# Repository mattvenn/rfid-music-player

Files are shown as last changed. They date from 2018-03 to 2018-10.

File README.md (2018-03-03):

# rfid music player

## components

* teensy 3.2
* adafruit i2s amp
* rfid rc522 reader
* sd card breakout
* string of leds - currently ws2812, but need to switch to a clocked version for
 compatibility with audio library.

## pin allocations

    teensy          i/o
    6               led data out
    7               mosi sd and rfid reader
    9               i2s bclk
    10              cs sd card
    12              miso sd and rfid

    14              sck sd and rfid
    15              rfid cs
    16              rfid reset
    21 (A7)         vol pot in
    22              i2s din
    23              i2s lrc

    3.3v            rfid psu and positive vol pot
    vin (5v)        i2s amp psu, led string +5v

## sd pinout

    1           n/c
    2           cs
    3           mosi    
    4           3.3v
    5           clk
    6           gnd
    7           miso
    8           n/c

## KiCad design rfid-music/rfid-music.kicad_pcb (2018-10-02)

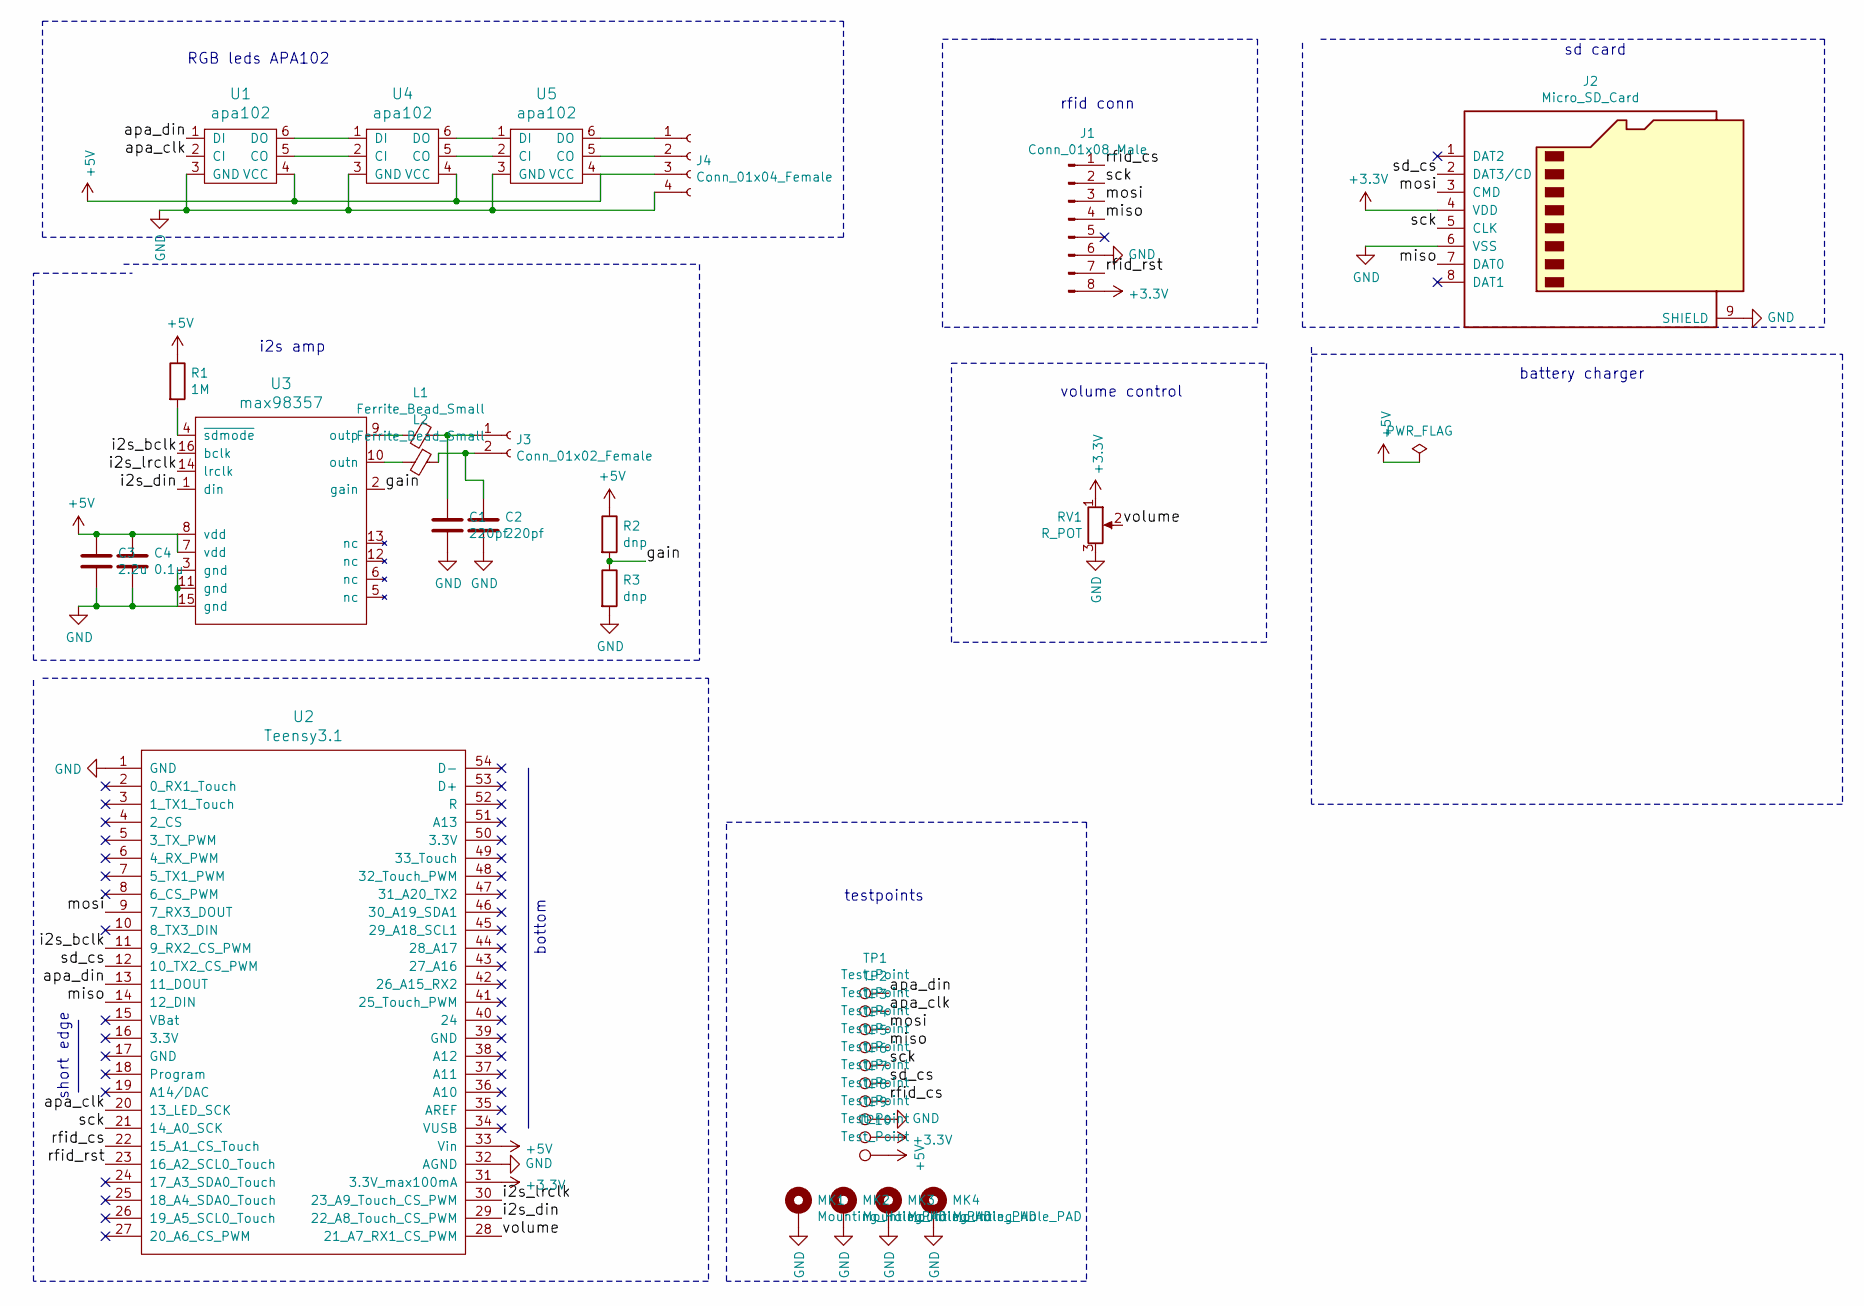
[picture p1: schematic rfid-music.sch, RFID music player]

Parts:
C1, C2: 220pf; C_0805_2012Metric
C3: 2.2u; C_0805_2012Metric
C4: 0.1u; C_0805_2012Metric
J1: Conn_01x08_Male; PinHeader_1x08_P2.54mm_Vertical
J2: Micro_SD_Card; microSD_HC_Hirose_DM3D-SF; farnell # 1764377
J3: Conn_01x02_Female; PinHeader_1x02_P2.54mm_Vertical
J4: Conn_01x04_Female; PinHeader_1x04_P2.54mm_Vertical
L1, L2: Ferrite_Bead_Small; L_0805_2012Metric
MK1, MK2, MK3, MK4: Mounting_Hole_PAD; MountingHole_3.2mm_M3_Pad
R1: 1M; R_0805_2012Metric
R2, R3: dnp; R_0805_2012Metric
RV1: R_POT; Potentiometer_Bourns_3314S_Horizontal; farnell # 1696070
TP1, TP2, TP3, TP4, TP5, TP6, TP7, TP8, TP9, TP10: Test_Point; Pin_D0.7mm_L6.5mm_W1.8mm_FlatFork
U1, U4, U5: apa102
U2: Teensy3.1; teensy31
U3: max98357; QFN-16-1EP_3x3mm_P0.5mm_EP2.7x2.7mm_ThermalVias

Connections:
+3V3: J1.8, J2.4 (VDD), RV1.1, TP9.1, U2.31 (3.3V_max100mA)
+5V: C3.1, C4.1, J4.3, R1.1, R2.1, TP10.1, U1.4 (VCC), U2.33 (Vin), U3.7 (vdd), U3.8 (vdd), U4.4 (VCC), U5.4 (VCC)
/apa_clk: TP2.1, U1.2 (CI), U2.20 (13_LED_SCK)
/apa_din: TP1.1, U1.1 (DI), U2.13 (11_DOUT)
/gain: R2.2, R3.1, U3.2 (gain)
/i2s_bclk: U2.11 (9_RX2_CS_PWM), U3.16 (bclk)
/i2s_din: U2.29 (22_A8_Touch_CS_PWM), U3.1 (din)
/i2s_lrclk: U2.30 (23_A9_Touch_CS_PWM), U3.14 (lrclk)
/miso: J1.4, J2.7 (DAT0), TP4.1, U2.14 (12_DIN)
/mosi: J1.3, J2.3 (CMD), TP3.1, U2.9 (7_RX3_DOUT)
/rfid_cs: J1.1, TP7.1, U2.22 (15_A1_CS_Touch)
/rfid_rst: J1.7, U2.23 (16_A2_SCL0_Touch)
/sck: J1.2, J2.5 (CLK), TP5.1, U2.21 (14_A0_SCK)
/sd_cs: J2.2 (DAT3/CD), TP6.1, U2.12 (10_TX2_CS_PWM)
/volume: RV1.2, U2.28 (21_A7_RX1_CS_PWM)
GND: C1.2, C2.2, C3.2, C4.2, J1.6, J2.6 (VSS), J2.9 (SHIELD), J4.4, MK1.1, MK2.1, MK3.1, MK4.1, R3.2, RV1.3, TP8.1, U1.3 (GND), U2.1 (GND), U2.32 (AGND), U3.3 (gnd), U3.11 (gnd), U3.15 (gnd), U4.3 (GND), U5.3 (GND)
unnamed: C1.1, J3.1, L1.1
unnamed: C2.1, J3.2, L2.1
unnamed: J4.1, U5.6 (DO)
unnamed: J4.2, U5.5 (CO)
unnamed: L1.2, U3.9 (outp)
unnamed: L2.2, U3.10 (outn)
unnamed: R1.2, U3.4 (~sdmode)
unnamed: U1.5 (CO), U4.2 (CI)
unnamed: U1.6 (DO), U4.1 (DI)
unnamed: U4.5 (CO), U5.2 (CI)
unnamed: U4.6 (DO), U5.1 (DI)

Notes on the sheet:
bottom
short edge
rfid conn
sd card
i2s amp
RGB leds APA102
volume control
battery charger
testpoints

Board: 2 copper layers, 33 parts (0 on the bottom side), 27 nets, no tracks yet.

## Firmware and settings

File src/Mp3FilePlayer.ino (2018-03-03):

// Simple WAV file player example
//
// Requires the audio shield:
//   http://www.pjrc.com/store/teensy3_audio.html
//
// This example code is in the public domain.

//#define FASTLED_INTERRUPT_RETRY_COUNT 1
#define FASTLED_ALLOW_INTERRUPTS 0
#include <Audio.h>
#include <Wire.h>
#include <SPI.h>
#include <SD.h>
#include <FastLED.h>
#define NUM_LEDS 8 // longer chains end up with corrupted leds
#define DATA_PIN 6

CRGB leds[NUM_LEDS];

typedef void (*SimplePatternList[])();
void start();
void wait();
void error();
void play();

SimplePatternList gPatterns = { start, wait, error, play };
#define FRAMES_PER_SECOND 100

#define START_PATTERN   0
#define WAIT_PATTERN    1
#define ERROR_PATTERN   2
#define PLAY_PATTERN    3

uint8_t led_pattern = START_PATTERN; // Index number of which pattern is current
uint8_t gHue = 0; // rotating "base color" used by many of the patterns

#include <play_sd_mp3.h>

// state machine defs
#define STATE_START         1
#define STATE_WAIT_STOP     2
#define STATE_PLAY_NEXT     3
#define STATE_WAIT_PLAY     4
#define STATE_PLAY_NO_CARD  5
#define STATE_SETUP_SD      6
#define STATE_SD_ERROR      7
#define STATE_WAIT_CHANGE_CARD      9

// pin defs
#define SD_SS               10

int state = STATE_START;

// GUItool: begin automatically generated code
AudioMixer4              mixer1;         //xy=641,541
AudioPlaySdMp3           playMp31;       //xy=154,78
AudioOutputI2S           i2s1;           //xy=334,89

AudioConnection          patchCord1(playMp31, 0, mixer1, 0);
AudioConnection          patchCord2(playMp31, 1, mixer1, 1);

AudioConnection          patchCord3(mixer1, 0, i2s1, 0);
AudioConnection          patchCord4(mixer1, 0, i2s1, 1);

AudioControlSGTL5000     sgtl5000_1;     //xy=240,153

String rfid = "";
String filename = "";
String dir_name = "";
File directory;
String last_rfid = "";

DEFINE_GRADIENT_PALETTE( error_gp ) {
  0,     0,  0,  0,   //black
128,   255,  0,  0,   //red
255,     0,  0,  0,   //black
};

DEFINE_GRADIENT_PALETTE( wait_gp ) {
  0,   255,  0,  255,   //purple
128,     0,  0,  255,   //blue
255,   255,  0,  255,   //purple
};

void start()
{
    FastLED.clear(); 
}
void wait()
{
    CRGBPalette16 myPal = wait_gp;
    int pos = beatsin16( 10, 0, NUM_LEDS-1 );
    leds[pos] = ColorFromPalette( myPal, gHue);
}

void error()
{
    CRGBPalette16 myPal = error_gp;
    fill_solid(leds, NUM_LEDS, ColorFromPalette( myPal, gHue));
}

void play()
{
    fadeToBlackBy( leds, NUM_LEDS, 20);
    int pos = beatsin16( 20, 0, NUM_LEDS-1 );
    leds[pos] += CHSV( gHue, 255, 255);
}

void setup() {
    Serial.begin(9600);
    //while(!Serial){;;}
    Serial.println("started");
    setup_rfid();

    FastLED.addLeds<WS2812, DATA_PIN, GRB>(leds, NUM_LEDS);
    FastLED.setBrightness(44);

    // Audio connections require memory to work.  For more
    // detailed information, see the MemoryAndCpuUsage example
    AudioMemory(5);

    sgtl5000_1.enable();

    led_pattern = PLAY_PATTERN; 
}


void loop() {
    gPatterns[led_pattern]();

    // send the 'leds' array out to the actual LED strip
    FastLED.show();  
    // insert a delay to keep the framerate modest
    FastLED.delay(1000/FRAMES_PER_SECOND); 

    // do some periodic updates
    EVERY_N_MILLISECONDS( 15 ) { gHue++; } // slowly cycle the "base color" through the rainbow

    EVERY_N_MILLISECONDS( 100) {
        // volume
        float vol = analogRead(7);
        vol = vol / 1024;
        mixer1.gain(0,vol);
        mixer1.gain(1,vol);
    }


    switch(state)
    {
        case STATE_START:
        {
            state = STATE_SETUP_SD;
            break;
        }
        case STATE_SETUP_SD:
            if(SD.begin(SD_SS))
                state = STATE_WAIT_STOP;
            else
                state = STATE_SD_ERROR;
            break;

        case STATE_SD_ERROR:
        {
            // stuck here forever
            // breath efffect: https://gist.github.com/hsiboy/4eae11073e9d5b21eae3
            led_pattern = ERROR_PATTERN;
            break;
        }
        case STATE_WAIT_STOP:
        {
            led_pattern = WAIT_PATTERN;

            if(read_rfid()) // returns true or false, updates the global rfid variable
            {
                if(!get_dir_from_rfid(rfid)) // returns true or false, updates the global filename variable
                    if(rfid != "")
                        append_new_rfid(rfid);   // add the rfid card to the index - sets the directory to the nocard directory

                state = STATE_PLAY_NEXT;
                Serial.print("playing directory: [");
                Serial.print(dir_name);
                Serial.println("]");
                directory = SD.open(dir_name.c_str());
                Serial.println(directory.isDirectory()); // TODO if this fails, do something. Can happen if the index file has a typo
            }
            break;
        }

        case STATE_WAIT_CHANGE_CARD:
            led_pattern = WAIT_PATTERN;
            read_rfid();
            if(rfid != last_rfid) // different card
                state = STATE_WAIT_STOP;
            break;

        case STATE_PLAY_NEXT:
            {
                File entry = directory.openNextFile();
                if (! entry) // no more files or this wasn't a directory
                {
                    state = STATE_WAIT_CHANGE_CARD;
                    Serial.println("no dir!");
                }
                else
                {
                    filename = dir_name + "/" + entry.name();
                    Serial.println(filename);
                    playMp31.play(filename.c_str());
                    state = STATE_WAIT_PLAY;
                }
                break;
            }

        case STATE_WAIT_PLAY:
            led_pattern = PLAY_PATTERN;

            if(!playMp31.isPlaying())
            {
                Serial.println("mp3 ended");
                state = STATE_PLAY_NEXT;
            }

            //Serial.print(AudioProcessorUsageMax());	 
            //Serial.println("% All");

            AudioProcessorUsageMaxReset();
            playMp31.processorUsageMaxReset();
            playMp31.processorUsageMaxResetDecoder();

            if(read_rfid())
            {
                if(rfid != last_rfid) // different card
                {
                    Serial.println("card changed");
                    playMp31.stop();
                    state = STATE_WAIT_STOP;
                }
                else
                    break;

            }
            else // card removed
            {
                Serial.println("card removed");
                playMp31.stop();
                state = STATE_WAIT_STOP;
            }

            break;
        
        default:
            Serial.println("no case!");
            break;
    }

}

bool get_dir_from_rfid(String rfid)
{
    Serial.println("opening");
    File index = SD.open("index.txt");
    String rfid_str = "";
    dir_name = ""; // null the global
    int count = 0;
    bool got_rfid = false;

    if(index) 
    {
        while(index.available()) 
        {
            char c = index.read();
            if(c == ',')
            {
                got_rfid = true;
            }
            else if(c == '\r')
            {} // just get rid of the character  
            else if(c == '\n')
            {
                Serial.print(count++);
                Serial.print(" ");
                Serial.print(rfid_str);
                Serial.print(",");
                Serial.println(dir_name);
                
                if(rfid == rfid_str)
                    return true;

                rfid_str = "";
                dir_name = "";
                got_rfid = false;
            }
            else if(got_rfid)
                dir_name.concat(String(c));
            else
                rfid_str.concat(String(c));

        }
        index.close();
        
    }

    return false;
}

// add new rfid to index, pointing to folder that contains 'not found' mp3
void append_new_rfid(String rfid)
{
    Serial.println("appending new rfid to index");
    dir_name = "nocard";
    File index = SD.open("index.txt", FILE_WRITE); // opens at the end of the file
    index.print(rfid);
    index.print(",");
    index.println(dir_name);
    index.close();
}

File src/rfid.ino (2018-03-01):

#include <SPI.h>
#include <MFRC522.h>

#define SS_PIN 15
#define RST_PIN 16
MFRC522 mfrc522(SS_PIN, RST_PIN);	// Create MFRC522 instance


void setup_rfid()
{
    SPI.begin();			// Init SPI bus
    SPI.setMOSI(7); SPI.setMISO(12); SPI.setSCK(14);
    mfrc522.PCD_Init();		// Init MFRC522
}

bool read_rfid()
{
    last_rfid = rfid;
    rfid = "";

    // this must be done for the card to continue reading a card that is left on the reader
    byte bufferATQA[2];
	byte bufferSize = sizeof(bufferATQA);
	byte result = mfrc522.PICC_WakeupA(bufferATQA, &bufferSize);
	if(result != mfrc522.STATUS_OK)
        return false;

	// Select one of the cards
	if ( ! mfrc522.PICC_ReadCardSerial())
    {
        Serial.println("no card");
		return false;
    }
	
    mfrc522.PICC_HaltA();
	for (byte i = 0; i < mfrc522.uid.size; i++) 
	{
		if(mfrc522.uid.uidByte[i] < 0x10)
		rfid.concat("0");
		rfid.concat(String(mfrc522.uid.uidByte[i], HEX));
	} 

    Serial.println(rfid);
	return true;
}

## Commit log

2018-03-01 switched to better spi reader: rc522
2018-03-02 status with leds
2018-03-02 tweaks in leds
2018-03-02 comment and remove serial print vol
2018-03-03 reduced number of leds to improve led reliability
2018-10-02 first commit on pcbs
    [rfid-music.kicad_pcb, rfid-music.sch]
